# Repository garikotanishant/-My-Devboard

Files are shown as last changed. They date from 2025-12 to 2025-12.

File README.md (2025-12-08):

My devboard is a RP2040-based development board designed for prototyping and electronics projects. It features USB-C connectivity, onboard flash memory, a crystal oscillator for precise timing, and multiple GPIO pins for connecting sensors, LEDs, and other components. The board is laid out to support high-speed signals like USB-C while keeping power and ground distribution efficient, making it suitable for a simple microcontroller project! It was very complex for me to build (even with the instructions 😅) but it was a great first project and I learned a lot.

### PCB
Screenshot 2025-12-07 at 8 07 14 PM

### Schematic
Screenshot 2025-12-07 at 7 00 23 PM

##### 3D View
Screenshot 2025-12-07 at 8 06 51 PM

##### PCB parts checkout
Screenshot 2025-12-07 at 9 55 21 PM

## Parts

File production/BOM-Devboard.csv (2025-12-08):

Id | Designator | Footprint | Quantity | Comment | Supplier and ref
1 | C6,C5,C4,C2,C7,C11,C9,C12,C17,C3,C8 | C_0402_1005Metric | 11 | 0.1uF
2 | C13,C14 | C_0603_1608Metric | 2 | 10uF
3 | Y1 | Crystal_SMD_3225-4Pin_3.2x2.5mm | 1 | 12 MHz
4 | C1,C10 | C_0402_1005Metric | 2 | 1uF
5 | R7 | R_0402_1005Metric | 1 | 10K
6 | C15,C16 | C_0402_1005Metric | 2 | 33pF
7 | R6,R5 | R_0402_1005Metric | 2 | 1K
8 | Boot | SW_Push_SPST_NO_Alps_SKRK | 1 | SW_Push
9 | J4 | PinHeader_1x03_P2.54mm_Vertical | 1 | J4
10 | R8 | R_0603_1608Metric | 1 | R
11 | LEDONE1 | LED_0603_1608Metric | 1 | LED
12 | R2,R1 | R_0402_1005Metric | 2 | 5.1K
13 | R3,R4 | R_0402_1005Metric | 2 | 27
14 | U1 | QFN-56-1EP_7x7mm_P0.4mm_EP3.2x3.2mm | 1 | RP2040
15 | J1 | USB_C_Receptacle_HRO_TYPE-C-31-M-12 | 1 | USB_C_Receptacle_USB2.0_14P
16 | J3,J2 | PinHeader_1x20_P2.54mm_Vertical | 2 | Conn_01x20
17 | U2 | SOT-23 | 1 | MCP1700x-330xxTT
18 | U4 | Winbond_USON-8-1EP_3x2mm_P0.5mm_EP0.2x1.6mm | 1 | W25Q16JVUXIQ TR

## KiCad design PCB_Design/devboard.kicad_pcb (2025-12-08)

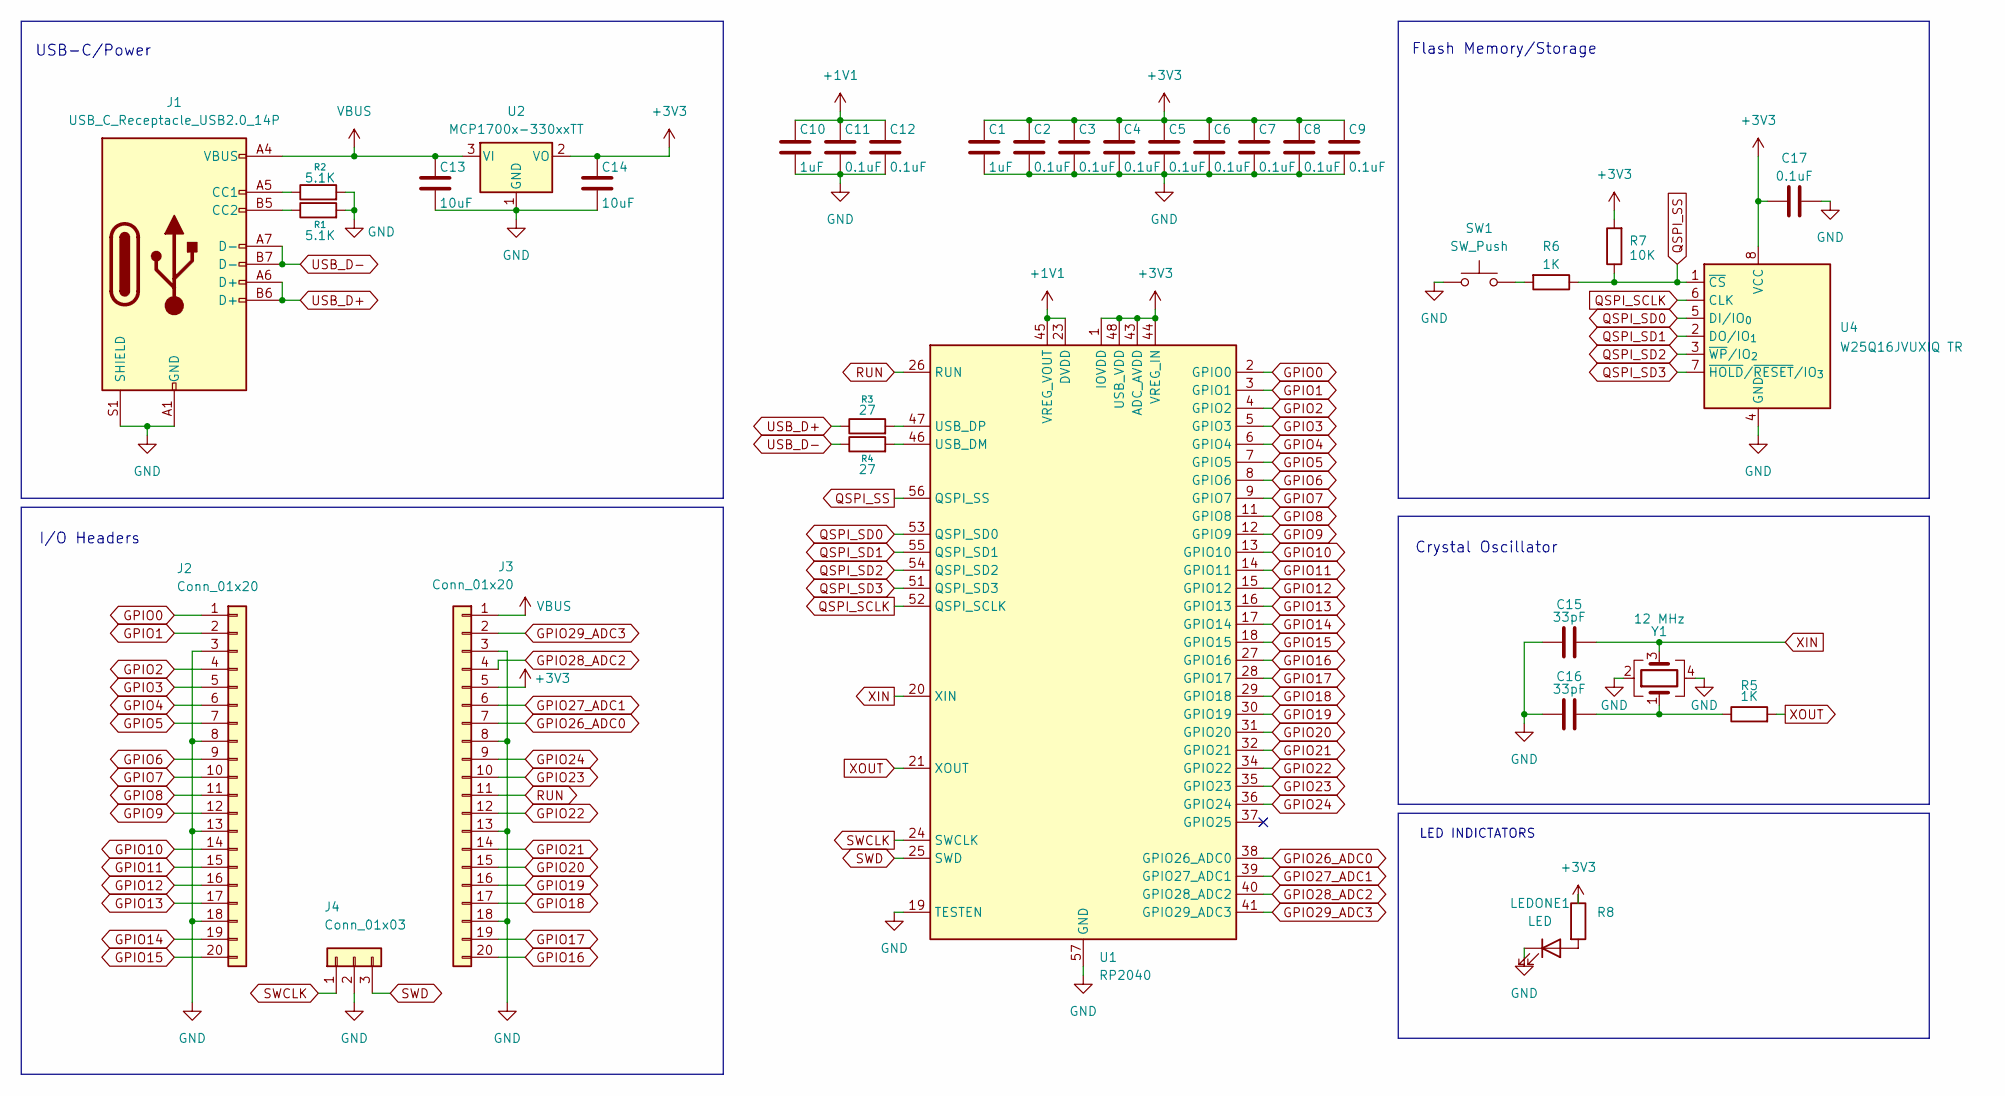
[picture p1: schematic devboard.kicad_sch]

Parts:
C1, C10: 1uF; C_0402_1005Metric
C2, C3, C4, C5, C6, C7, C8, C9, C11, C12, C17: 0.1uF; C_0402_1005Metric
C13, C14: 10uF; C_0603_1608Metric
C15, C16: 33pF; C_0402_1005Metric
J1: USB_C_Receptacle_USB2.0_14P; USB_C_Receptacle_HRO_TYPE-C-31-M-12
J2, J3: Conn_01x20; PinHeader_1x20_P2.54mm_Vertical
J4: Conn_01x03; PinHeader_1x03_P2.54mm_Vertical
LEDONE1: LED; LED_0603_1608Metric
R1, R2: 5.1K; R_0402_1005Metric
R3, R4: 27; R_0402_1005Metric
R5, R6: 1K; R_0402_1005Metric
R7: 10K; R_0402_1005Metric
R8: R; R_0603_1608Metric
SW1: SW_Push; SW_Push_SPST_NO_Alps_SKRK
U1: RP2040; QFN-56-1EP_7x7mm_P0.4mm_EP3.2x3.2mm
U2: MCP1700x-330xxTT; SOT-23
U4: W25Q16JVUXIQ TR; Winbond_USON-8-1EP_3x2mm_P0.5mm_EP0.2x1.6mm
Y1: 12 MHz; Crystal_SMD_3225-4Pin_3.2x2.5mm

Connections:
+1V1: C10.1, C11.1, C12.1, U1.23 (DVDD), U1.45 (VREG_VOUT), U1.50 (DVDD)
GND: C1.2, C2.2, C3.2, C4.2, C5.2, C6.2, C7.2, C8.2, C9.2, C10.2, C11.2, C12.2, C13.2, C14.2, C15.1, C16.1, C17.2, J1.A1 (GND), J1.A12 (GND), J1.B1 (GND), J1.B12 (GND), J1.S1 (SHIELD), J2.3, J2.8, J2.13, J2.18, J3.3, J3.8, J3.13, J3.18, J4.2, LEDONE1.1 (K), R1.2, R2.2, SW1.1, U1.19 (TESTEN), U1.57 (GND), U2.1 (GND), U4.4 (GND), Y1.2, Y1.4; also elsewhere on the board
GPIO1: J2.2, U1.3 (GPIO1)
GPIO2: J2.4, U1.4 (GPIO2)
GPIO3: J2.5, U1.5 (GPIO3)
GPIO4: J2.6, U1.6 (GPIO4)
GPIO5: J2.7, U1.7 (GPIO5)
GPIO6: J2.9, U1.8 (GPIO6)
GPIO7: J2.10, U1.9 (GPIO7)
GPIO8: J2.11, U1.11 (GPIO8)
GPIO9: J2.12, U1.12 (GPIO9)
GPIO10: J2.14, U1.13 (GPIO10)
GPIO11: J2.15, U1.14 (GPIO11)
GPIO12: J2.16, U1.15 (GPIO12)
GPIO13: J2.17, U1.16 (GPIO13)
GPIO14: J2.19, U1.17 (GPIO14)
GPIO15: J2.20, U1.18 (GPIO15)
GPIO16: J3.20, U1.27 (GPIO16)
GPIO17: J3.19, U1.28 (GPIO17)
GPIO18: J3.17, U1.29 (GPIO18)
GPIO19: J3.16, U1.30 (GPIO19)
GPIO20: J3.15, U1.31 (GPIO20)
GPIO21: J3.14, U1.32 (GPIO21)
GPIO22: J3.12, U1.34 (GPIO22)
GPIO23: J3.10, U1.35 (GPIO23)
GPIO24: J3.9, U1.36 (GPIO24)
GPIO26_ADC0: J3.7, U1.38 (GPIO26_ADC0)
GPIO27_ADC1: J3.6, U1.39 (GPIO27_ADC1)
GPIO28_ADC2: J3.4, U1.40 (GPIO28_ADC2)
GPIO29_ADC3: J3.2, U1.41 (GPIO29_ADC3)
unnamed: C16.2, R5.1, Y1.1
unnamed: J1.A5 (CC1), R2.1
unnamed: J1.B5 (CC2), R1.1
unnamed: LEDONE1.2 (A), R8.2
unnamed 34: R6.2, SW1.2; also elsewhere on the board
unnamed: R4.2, U1.46 (USB_DM)
unnamed: R3.2, U1.47 (USB_DP)
QSPI_SCLK: U1.52 (QSPI_SCLK), U4.6 (CLK)
QSPI_SD0: U1.53 (QSPI_SD0), U4.5 (DI/IO_{0})
QSPI_SD1: U1.55 (QSPI_SD1), U4.2 (DO/IO_{1})
QSPI_SD2: U1.54 (QSPI_SD2), U4.3 (~WP/IO_{2})
QSPI_SD3: U1.51 (QSPI_SD3), U4.7 (~HOLD/~RESET/IO_{3})
QSPI_SS: R6.1, R7.1, U1.56 (QSPI_SS), U4.1 (~CS)
RUN: J3.11, U1.26 (RUN)
SWCLK: J4.1, U1.24 (SWCLK)
SWD: J4.3, U1.25 (SWD)
USB_D+: J1.A6 (D+), J1.B6 (D+), R3.1
USB_D-: J1.A7 (D-), J1.B7 (D-), R4.1
VBUS: C13.1, J1.A4 (VBUS), J1.A9 (VBUS), J1.B4 (VBUS), J1.B9 (VBUS), J3.1, U2.3 (VI)
XIN: C15.2, U1.20 (XIN), Y1.3
XOUT: R5.2, U1.21 (XOUT)

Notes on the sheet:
Flash Memory/Storage
I/O Headers
LED INDICTATORS
Crystal Oscillator
USB-C/Power

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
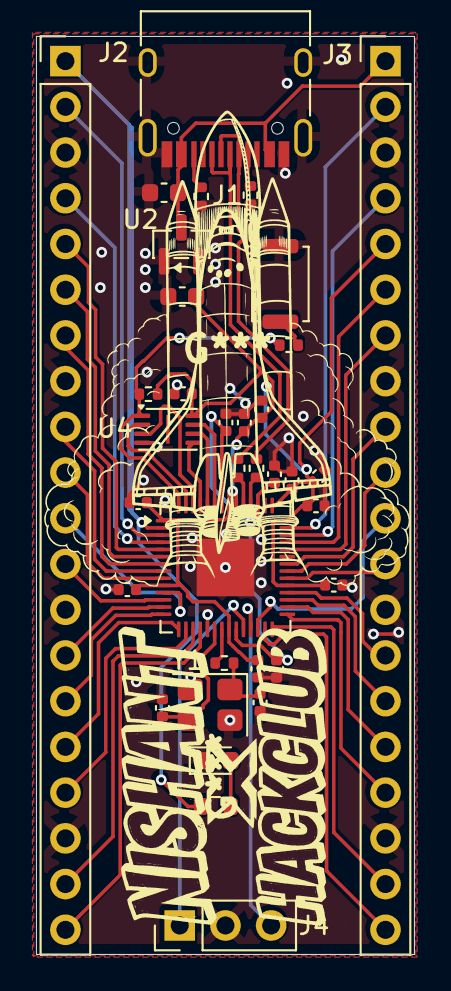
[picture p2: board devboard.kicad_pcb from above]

Board: 2 copper layers, 21.0 x 51.0 mm, 35 parts (0 on the bottom side), 53 nets.

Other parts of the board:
Boot: SW_Push; SW_Push_SPST_NO_Alps_SKRK

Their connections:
GND: Boot.1; also elsewhere on the board
unnamed 34: Boot.2; also elsewhere on the board
